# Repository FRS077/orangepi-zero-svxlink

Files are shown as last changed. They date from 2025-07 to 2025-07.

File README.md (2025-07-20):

# Shield OrangePi zero SvxLink

The purpose of this PCB is to easily interface one or two radio transceivers with an Orange Pi Zero. This makes it easy to create a simplex or duplex SvxLink access point.

It is assembled on top of the Orange Pi Zero and connected to the radios by two mini DIN connectors.

## Built With

- KiCad v7 - _Open Source CAD software_
- KiCad v7 Librairies - _Symbols, footprints and 3D models librairies_
- LCSC - _Electronic parts provider_ & JLCPCB - _Board manufacturing_

## Specifications

### Mini DIN Pinout

| No Pin | Simplex / Duplex RX | Duplex TX |
| :----: | :---: | :---: |
| 1 | Audio Out | Audio Out |
| 2 | Ground |  Ground |
| 3 | PTT | PTT |
| 4 | Audio In (9600) | _N/C_ |
| 5 | Audio In (1200) | _N/C_ |
| 6 | Squelch | _N/C_ |

PTT is connected on the Orange Pi Zero to PA07 and Squelch to PA10.

### Solder bridge selectors

| Name  | Usage | Choice A | Choice B |
| :---: | :--- | :---: | :---: |
|  JP1  | Select the audio input | Audio In 1200 _(default)_ | Audio In 9600 |
|  JP2  | Select simplex/duplex mode (audio output) | Duplex mode |  Simplex mode |
|  JP3  | Select simplex/duplex mode (PTT) | Duplex mode |  Simplex mode |

## Authors

- **Quentin Rahms** - _Intial work_
- **Alexis Moyart** - _Completion_

## License

This project is licensed under the MIT License - see the LICENSE.md file for details

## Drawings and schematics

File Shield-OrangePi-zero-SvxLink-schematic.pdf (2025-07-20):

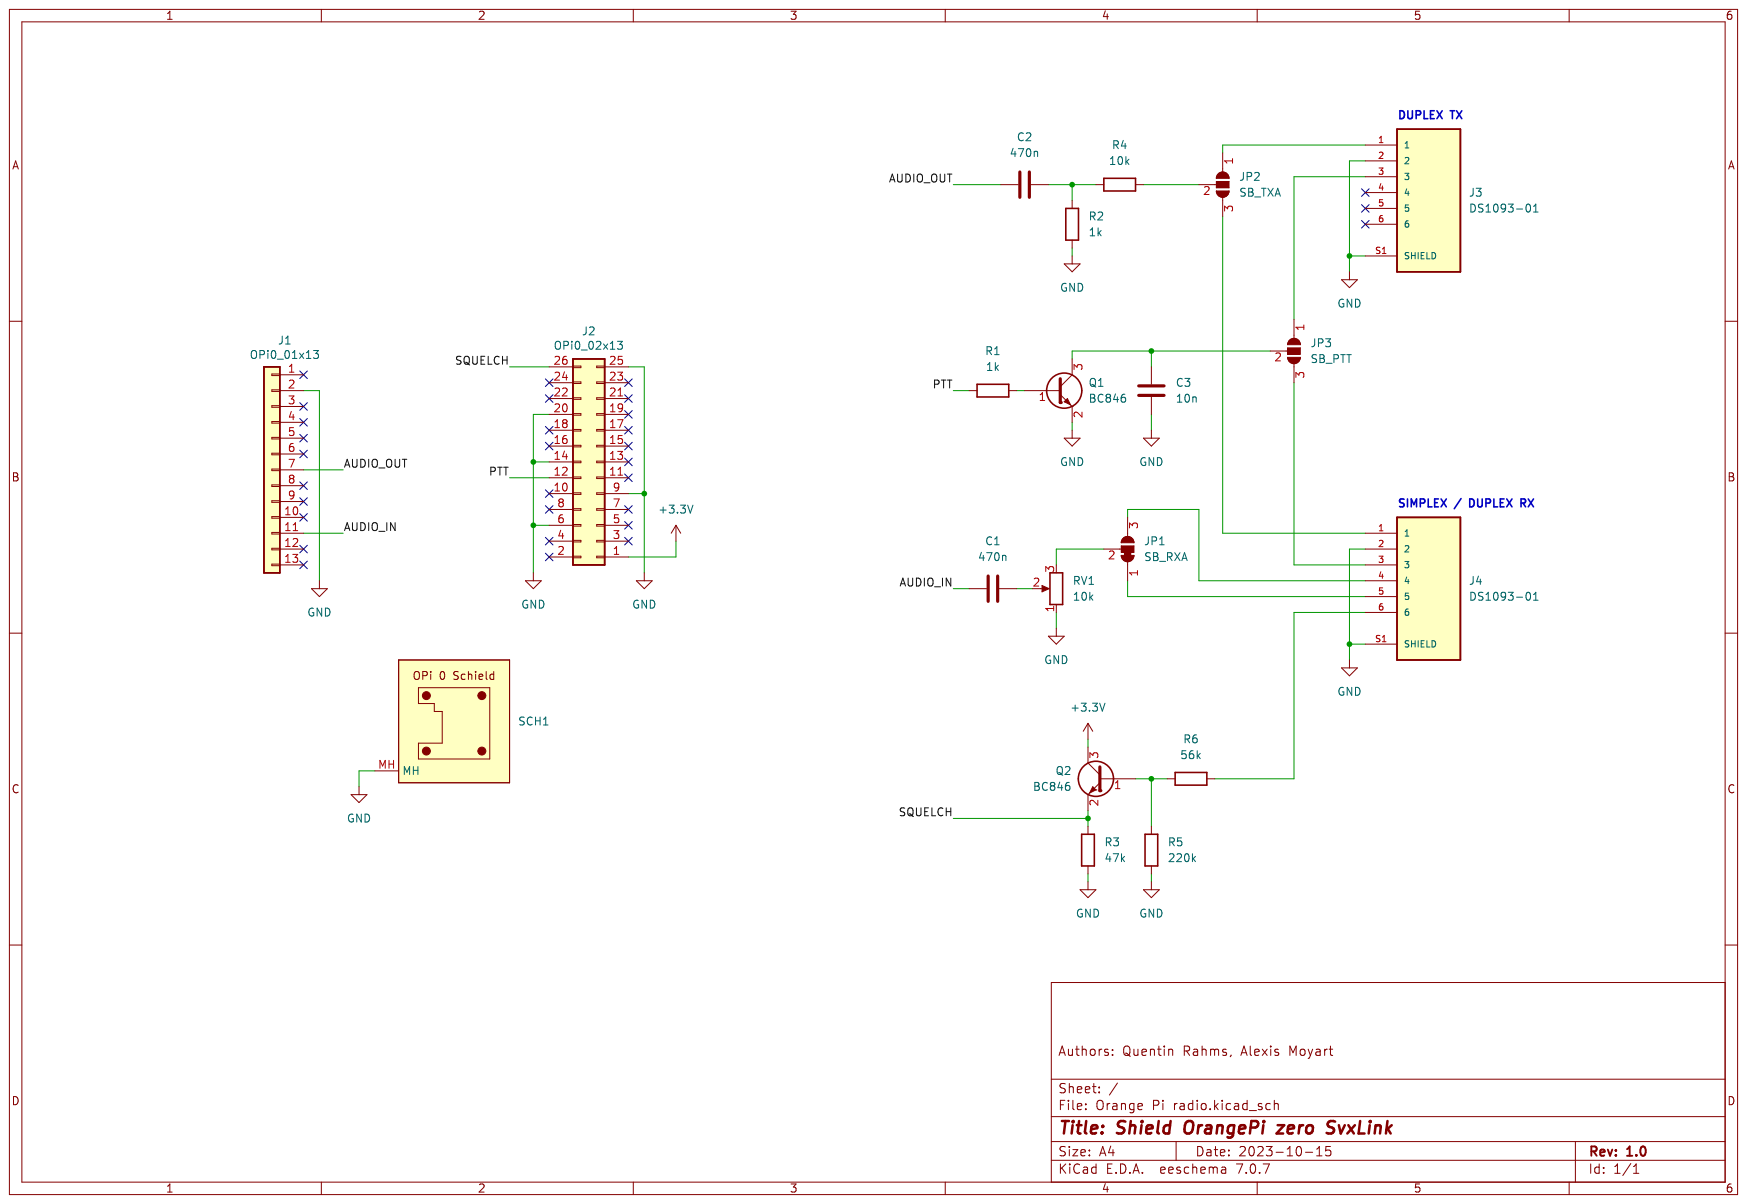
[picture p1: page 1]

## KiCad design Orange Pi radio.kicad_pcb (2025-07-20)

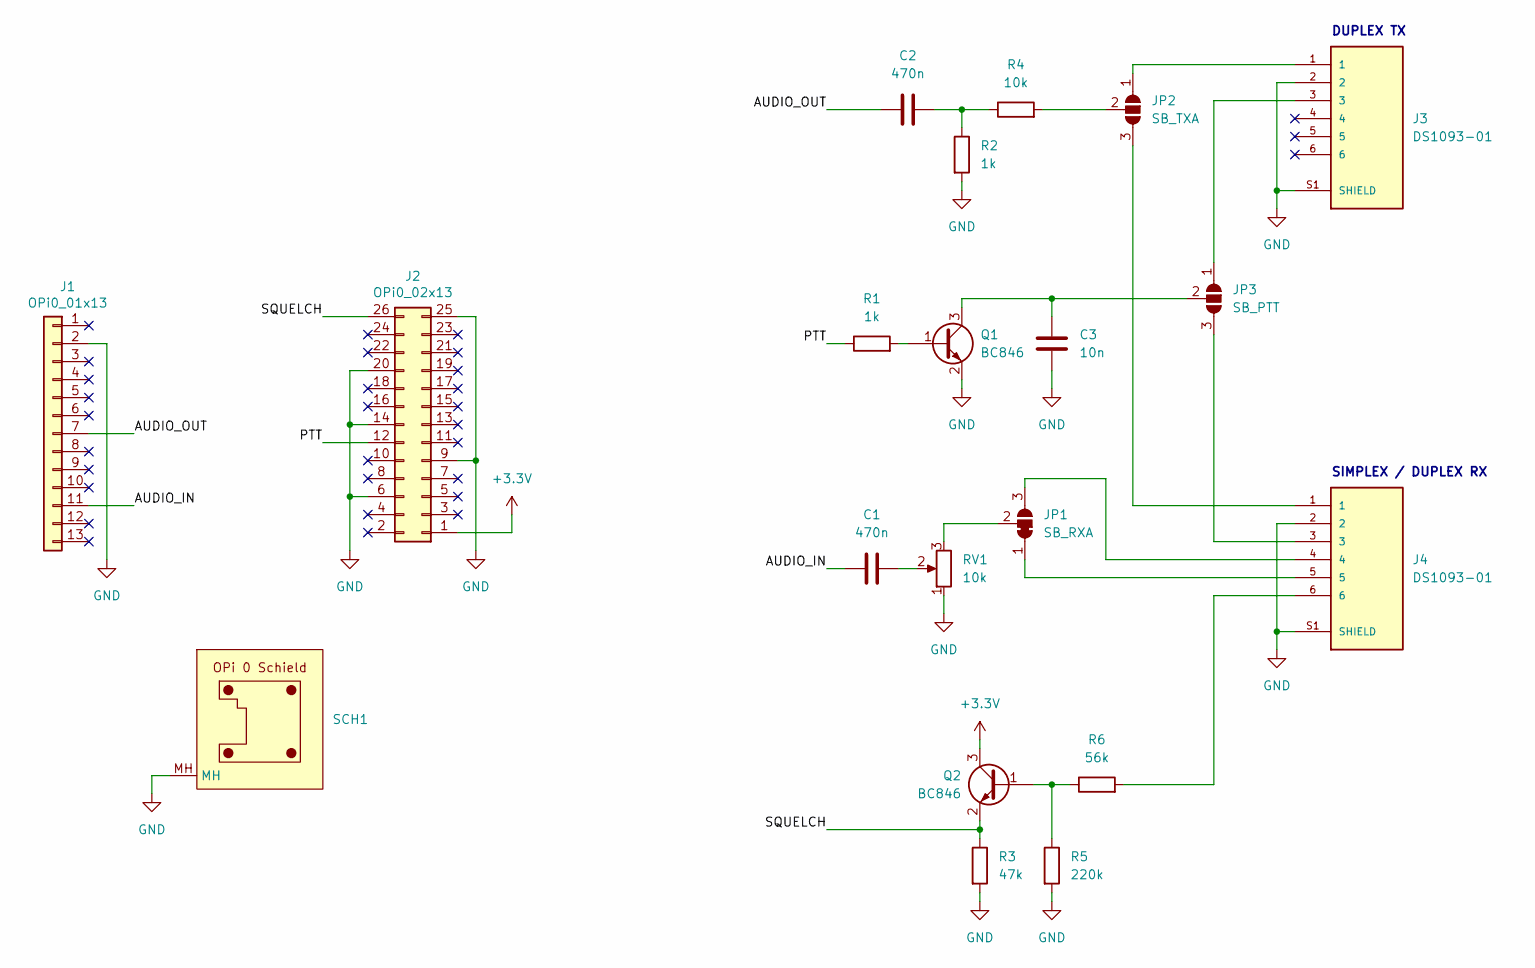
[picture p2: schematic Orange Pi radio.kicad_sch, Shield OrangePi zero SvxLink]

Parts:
C1, C2: 470n; C_0603_1608Metric_Pad1.08x0.95mm_HandSolder
C3: 10n; C_0603_1608Metric_Pad1.08x0.95mm_HandSolder
J1: OPi0_01x13; PinSocket_1x13_P2.54mm_Vertical
J2: OPi0_02x13; PinSocket_2x13_P2.54mm_Vertical
J3, J4: DS1093-01
JP1: SB_RXA; SolderJumper-3_P1.3mm_Bridged12_RoundedPad1.0x1.5mm
JP2: SB_TXA; SolderJumper-3_P1.3mm_Open_RoundedPad1.0x1.5mm
JP3: SB_PTT; SolderJumper-3_P1.3mm_Open_RoundedPad1.0x1.5mm
Q1, Q2: BC846; SOT-23
R1, R2: 1k; R_0603_1608Metric_Pad0.98x0.95mm_HandSolder
R3: 47k; R_0603_1608Metric_Pad0.98x0.95mm_HandSolder
R4: 10k; R_0603_1608Metric_Pad0.98x0.95mm_HandSolder
R5: 220k; R_0603_1608Metric_Pad0.98x0.95mm_HandSolder
R6: 56k; R_0603_1608Metric_Pad0.98x0.95mm_HandSolder
RV1: 10k; Potentiometer_Bourns_3314G_Vertical
SCH1: OPi0_schield

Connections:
+3.3V: J2.1, Q2.3 (C)
/AUDIO_IN: C1.1, J1.11
/AUDIO_OUT: C2.1, J1.7
/PTT: J2.12, R1.1
/SQUELCH: J2.26, Q2.2 (E), R3.1
GND: C3.2, J1.2, J2.6, J2.9, J2.14, J2.20, J2.25, J3.2, J3.S1 (SHIELD), J3.S2 (SHIELD), J3.S3 (SHIELD), J4.2, J4.S1 (SHIELD), J4.S2 (SHIELD), J4.S3 (SHIELD), Q1.2 (E), R2.2, R3.2, R5.2, RV1.1, SCH1.MH
unnamed: C1.2, RV1.2
unnamed: C2.2, R2.1, R4.1
unnamed: J4.6, R6.2
unnamed: J4.5, JP1.1 (A)
unnamed: J4.4, JP1.3 (B)
unnamed: JP1.2 (C), RV1.3
unnamed: J3.1, JP2.1 (A)
unnamed: J4.1, JP2.3 (B)
unnamed: JP2.2 (C), R4.2
unnamed: J3.3, JP3.1 (A)
unnamed: J4.3, JP3.3 (B)
unnamed: C3.1, JP3.2 (C), Q1.3 (C)
unnamed: Q1.1 (B), R1.2
unnamed: Q2.1 (B), R5.1, R6.1

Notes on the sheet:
SIMPLEX / DUPLEX RX
DUPLEX TX

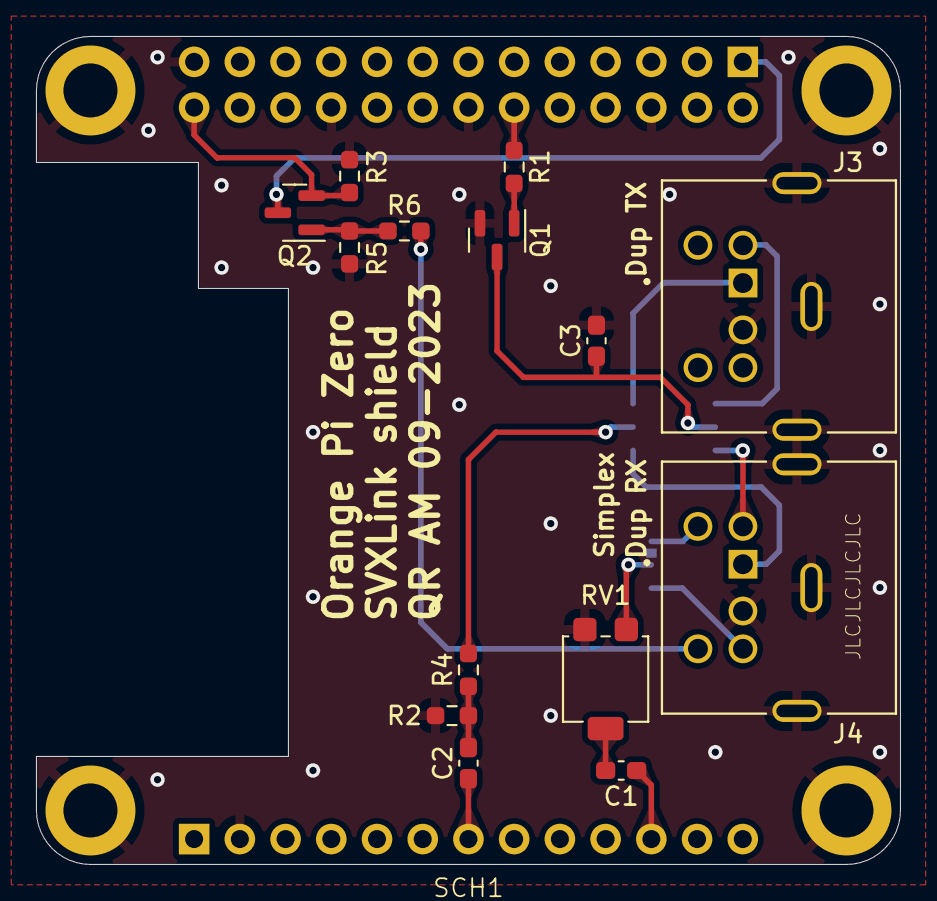
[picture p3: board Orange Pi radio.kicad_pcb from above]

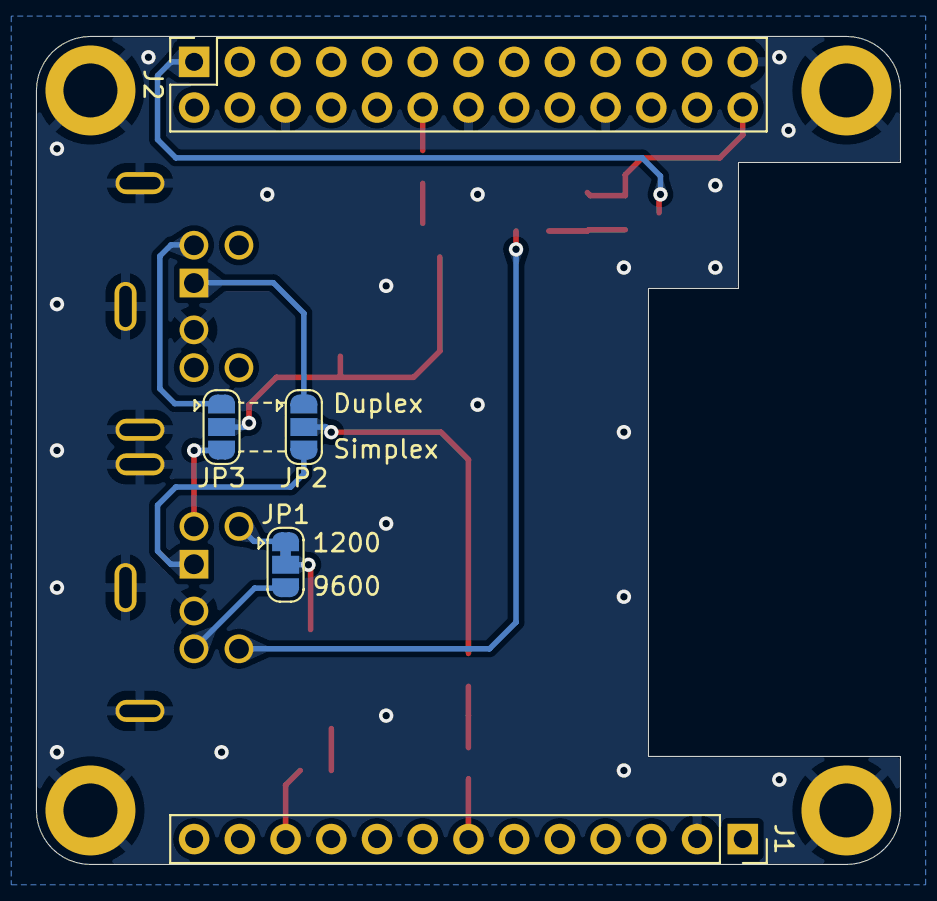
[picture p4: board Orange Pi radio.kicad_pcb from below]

Board: 2 copper layers, 48.0 x 46.0 mm, 20 parts (5 on the bottom side), 20 nets.
